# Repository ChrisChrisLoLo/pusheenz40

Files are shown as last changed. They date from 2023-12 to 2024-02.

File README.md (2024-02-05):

# pusheenz40
An experimental ultraportable pocket keyboard that uses low profile SMD mouse switches (EVQP0N02B) to achieve a compact form factor (8mm thick) while still being viable as a daily use keyboard (85+ wpm). Entire PCBA can be produced by JLCPCB. Uses 3D printed keycaps.

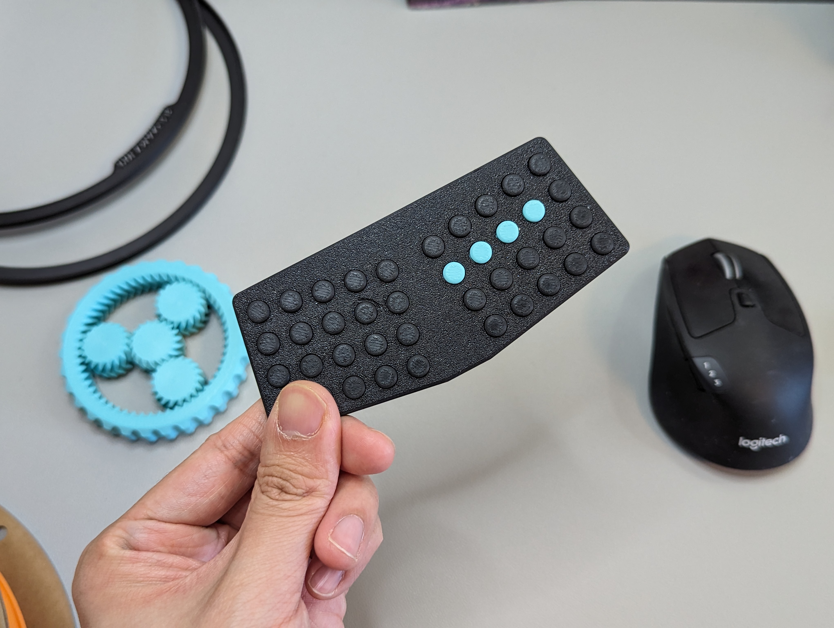
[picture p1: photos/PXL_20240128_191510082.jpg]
a photo of a pusheenz40


# Status
v0.0 PCBs are working! A pcb produced from the files should work.

Disclaimer is that this design has very low tolerances for its key switches. You will likely need a 3D printer such as a Bambu Lab A1/A1 mini/P1P/P1S and set the slicing layer resolution to 0.08mm. Printers like the Prusa i3/mini may also work, but have not been tested.

If you want to assemble/order your own PCBAs, come chat in the discord here! https://discord.gg/m8vwnqJEsc

# About
I hit the limit as how small I could go with choc switches. For my bunchiez40 and modkipz40, I used kailh mute switches as a smaller alternative. While a good start, these switches are both fairly tall and not super comfortable to type on directly. This board alternatively uses SMD EVQP0N02B switches from LCSC, which lowers the board height considerably, and reduces manual assembly required. This board also uses 3D printed buttons, which makes keypresses more comfortable.

More details about my research on mouse switches and experience with the pusheenz40 can be found here: https://chrischrislolo.github.io/orthoLabLogs/pusheenz40.html

Case files include 3MF files, STEP files that include the top case housing, as well as the buttons.

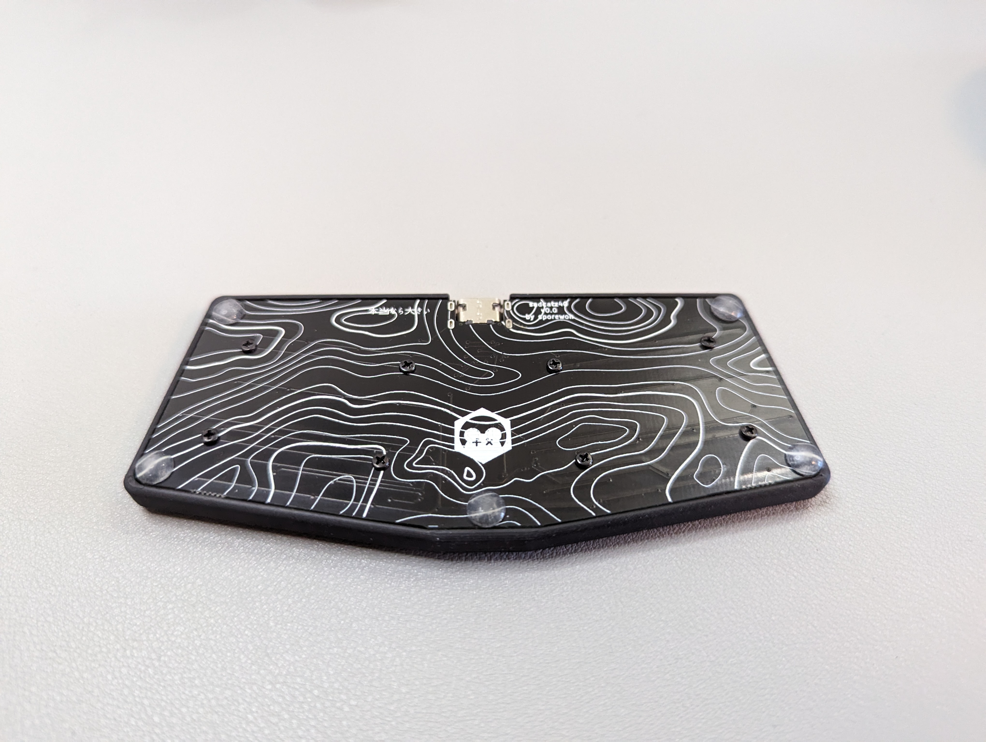
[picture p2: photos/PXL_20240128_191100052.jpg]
a pusheenz40


# Case
The case files can be found in the `case` directory. There is either the inverted rails or simple rails model to choose from. The simple rails model can be cnc'd, but has a rare tendency to have the buttons stick when pressed at a weird angle (1/1000 presses, as a rough guage of frequency). The inverted rails model has less of this issue, but cannot be cnc'd due to its sharp edges. I currently daily drive with the simple rails model.

3D printed cases can and should use the finest resolution possible on your printer, and ideally should use a higher end printer due to it's low tolerances. The models have been tested to work with the Bambu lab A1 and P1S at a layer height and detail setting of 0.08mm (extra fine). It's recommended to use a high quality and/or a newer printer.

Lubricating the case rails with something like krytox 205g0 is recommended, especially when using a CNC aluminum case. 

## PCB
You can find the PCB source files in the `pcb` folder. The BOM files can be found in this folder.

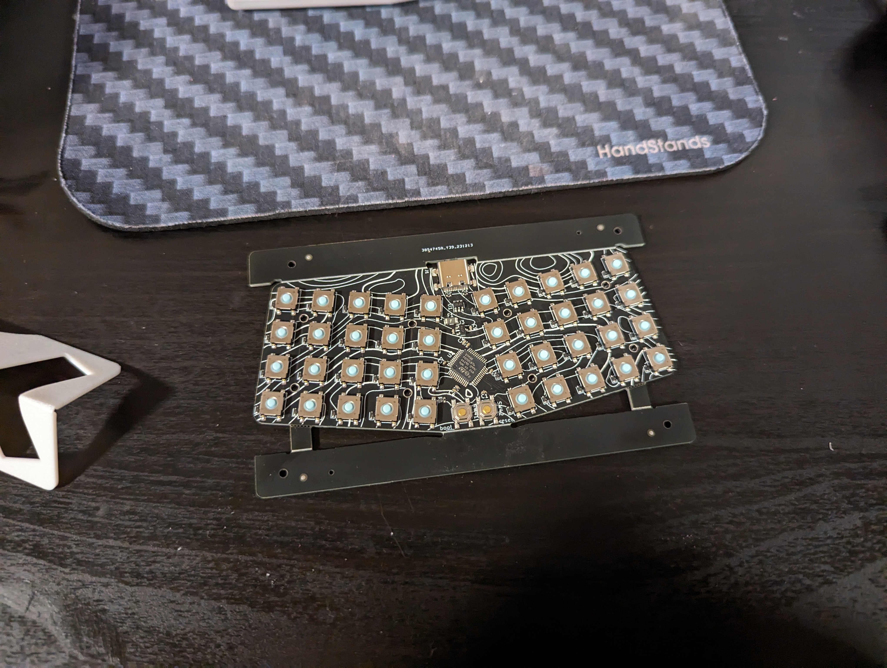
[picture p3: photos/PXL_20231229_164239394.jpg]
pusheenz40 pcb


## Directory Structure
- `case`
    You can find the files you need in this folder to print out a case for the keyboard
- `drafts`
    Stores any ergogen or intermediate information used in making the case
- `pcb`
    Kicad project relating to the project. Contains the BOM, placement files, and gerbers
   
## BOM
- 1 PCBA
  - The PCB will include all electrical parts required, including switches.
- 1 Aluminum CNC upper case or 3DP upper case
- 40 3D printed buttons
- 8 3mm M1.6 screws (go for flathead for a more flush fit, though other head types should also work)
- 4-8 (ideally 8) 1-2mm bumpons (something like Sj5302 is a good place to start)

## Assembly
Flash the pcb via QMK (see below section). Bootmagic is enabled, so using the top left key to flash from here on out is doable.

Pop the 3D printed buttons/keycaps into the case, and make sure they don't stick and can freely move up and down. If they do stick (e.g. need noticable force applied to pop out), confirm that you're printing at the finest detail setting. All keys need to be flush against the case. Once the switches are in place, over lap the pcb over the case. Gently press the pcb to make sure a button isn't pressed down.

Optionally wrap the board with a rubber band to hold it in place and flip it over to validate everything. Then gently press every button to make sure if it can actuate. If a button is very sticky, reprinting or sanding may be required. If there's slight friction on the keys return, this should slowly go away as the keyboard is broken in. If there's a button that won't actuate, it's possible that the button is misaligned. Flip the board back around, remove the rubber band and pcb, and make sure the problematic key is flush against the case. Place back pcb around and test until all keys properly acutate.

Then turn the keybard around one last time so the pcb is facing upwards. Screw on the screws and test one last time.

Finally, place on the rubber bumpons

## Firmware
QMK Firmware can be found here
https://github.com/ChrisChrisLoLo/vial-qmk/tree/sporewoh/keyboards/sporewoh/pusheenz40

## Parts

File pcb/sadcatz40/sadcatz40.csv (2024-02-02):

Id | Designator | Footprint | Quantity | Designation | Supplier and ref
1 | D36,D33,D10,D23,D17,D5,D37,D1,D4,D18,D12,D7,D22,D6,D2,D14,D11,D19,D39,D13,D31,D40,D16,D15,D29,D8,D38,D26,D27,D24,D9,D30,D25,D34,D32,D21,D28,D35,D20,D3 | D_SOD-523 | 40 | D_Small
2 | SW2,SW32,SW10,SW20,SW8,SW19,SW38,SW15,SW21,SW1,SW36,SW29,SW25,SW31,SW11,SW13,SW4,SW34,SW17,SW18,SW33,SW40,SW30,SW7,SW14,SW12,SW5,SW3,SW24,SW16,SW28,SW37,SW9,SW39,SW26,SW22,SW23,SW27,SW35,SW6 | SW_SPST_EVQP0 | 40 | SW_Push
3 | SW41 | SW_SPST_SKQG_WithoutStem | 1 | BOOT
4 | C10,C3,C9 | C_0402_1005Metric | 3 | 1uF
5 | U1 | SOT-23-6 | 1 | USBLC6-2SC6
6 | H3,H6,H2,H1,H4,H7,H8,H5 | m1.6_hole | 8 | MountingHole_Pad
7 | C7,C1,C5,C6,C4 | C_0402_1005Metric | 5 | 100nF
8 | R1 | R_0402_1005Metric | 1 | 10k
9 | C2 | C_0402_1005Metric | 1 | 4.7uF
10 | SW42 | SW_SPST_SKQG_WithoutStem | 1 | RST
11 | J1 | Mid_Mount-USB_C | 1 | USB2_C_Receptacle
12 | R2,R3 | R_0402_1005Metric | 2 | 5.1k
13 | U2 | LQFP-48_7x7mm_P0.5mm | 1 | STM32F072C8Tx
14 | U3 | SOT-23 | 1 | XC6206PxxxMR-Regulator_Linear
15 | F1 | Fuse_1206_3216Metric | 1 | 500mA

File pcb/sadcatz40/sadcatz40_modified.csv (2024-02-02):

Designator | Footprint | Comment | JLCPCB Part #
J1 | Mid_Mount-USB_C | USB2_C_Receptacle | C223907
C4,C6,C5,C1,C7 | C_0402_1005Metric | 100nF | C1525
D3,D20,D35,D28,D21,D32,D34,D25,D30,D9,D24,D27,D26,D38,D8,D29,D15,D16,D40,D31,D13,D39,D19,D11,D14,D2,D6,D22,D7,D12,D18,D4,D1,D37,D5,D17,D23,D33,D10,D36 | D_SOD-523 | D_Small | C145179
SW2,SW32,SW10,SW20,SW8,SW19,SW38,SW15,SW21,SW1,SW36,SW29,SW25,SW31,SW11,SW13,SW4,SW34,SW17,SW18,SW33,SW40,SW30,SW7,SW14,SW12,SW5,SW3,SW24,SW16,SW28,SW37,SW9,SW39,SW26,SW22,SW23,SW27,SW35,SW6 | SW_SPST_EVQP0 | SW_Push | C713479
C9,C3,C10 | C_0402_1005Metric | 1uF | C52923
F1 | Fuse_1206_3216Metric | 500mA | C163512
R3,R2 | R_0402_1005Metric | 5.1k | C25905
U3 | SOT-23 | XC6206PxxxMR-Regulator_Linear | C5446
U2 | LQFP-48_7x7mm_P0.5mm | STM32F072C8Tx | C80488
SW42 | SW_SPST_SKQG_WithoutStem | RST | C318884
C2 | C_0402_1005Metric | 4.7uF | C23733
R1 | R_0402_1005Metric | 10k | C25744
U1 | SOT-23-6 | USBLC6-2SC6 | C5250994
SW41 | SW_SPST_SKQG_WithoutStem | BOOT | C318884

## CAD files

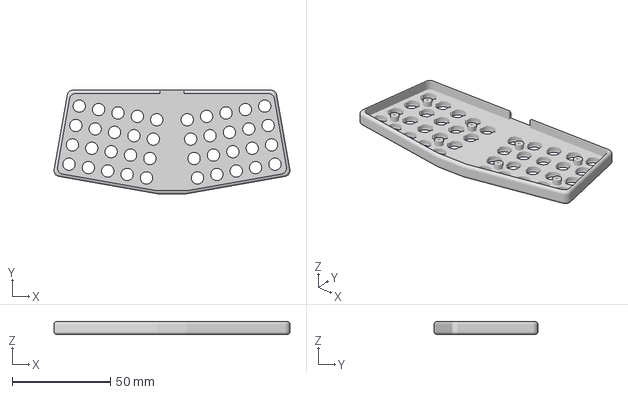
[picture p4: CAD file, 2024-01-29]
case/inverted_rails/pusheenz40 low tolerance v5 case.3mf
120.0 x 52.7 x 6.70 mm

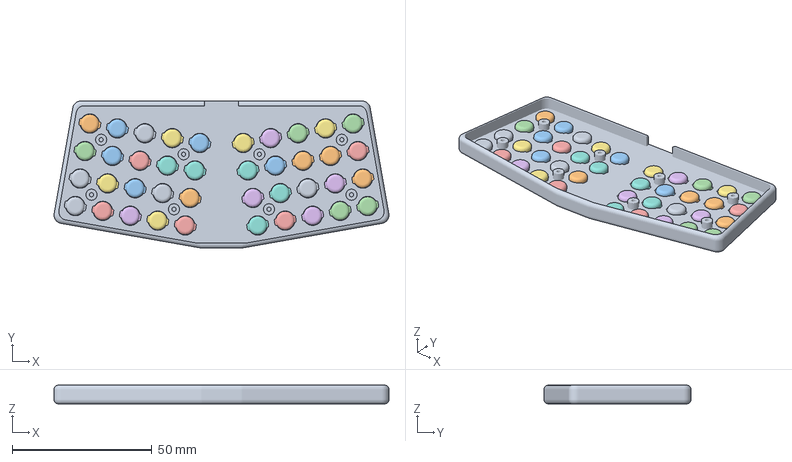
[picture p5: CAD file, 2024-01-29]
case/simple_rails/pusheenz40 low tolerance v2 v8.3mf
120.0 x 52.7 x 6.70 mm

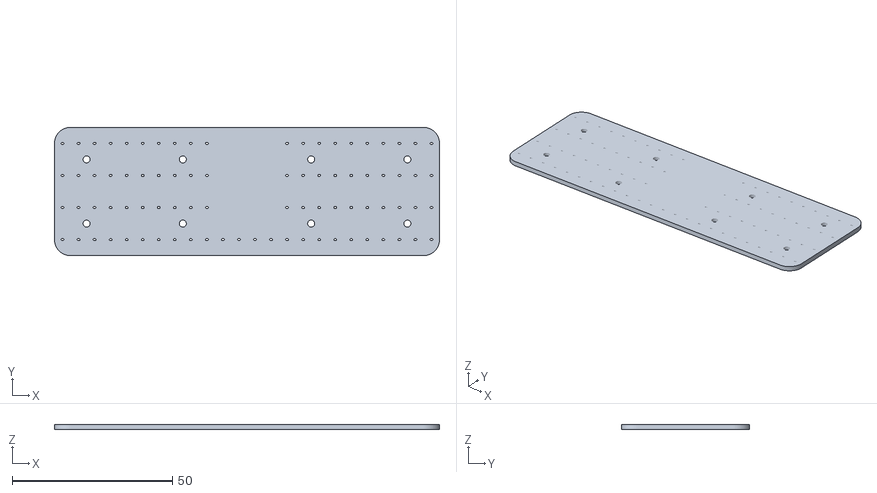
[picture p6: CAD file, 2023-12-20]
pcb/sadcatz40/pcb_prototype.stl
120.0 x 40.0 x 1.60

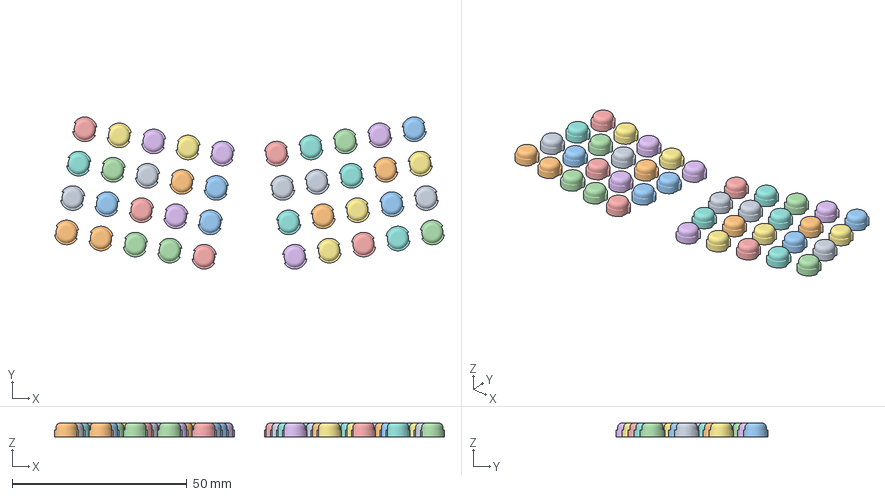
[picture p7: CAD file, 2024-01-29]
case/inverted_rails/pusheenz40 low tolerance v5.3mf
111.7 x 43.5 x 4.00 mm

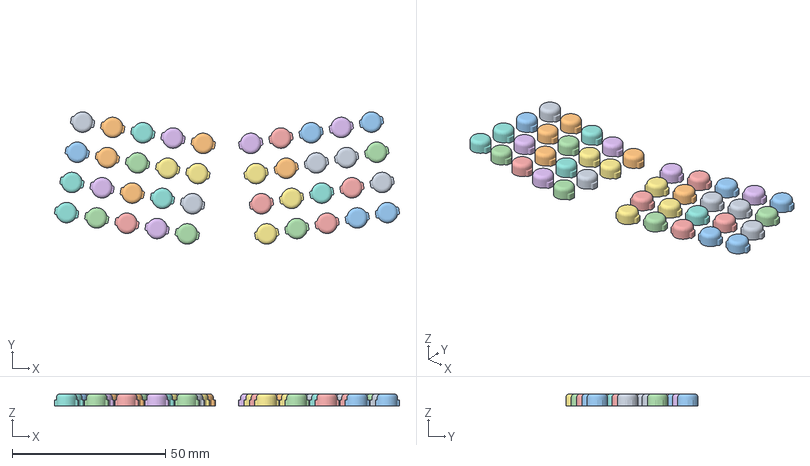
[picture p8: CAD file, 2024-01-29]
case/simple_rails/pusheenz40 low tolerance v2 v8 keycaps.3mf
112.6 x 43.2 x 4.00 mm

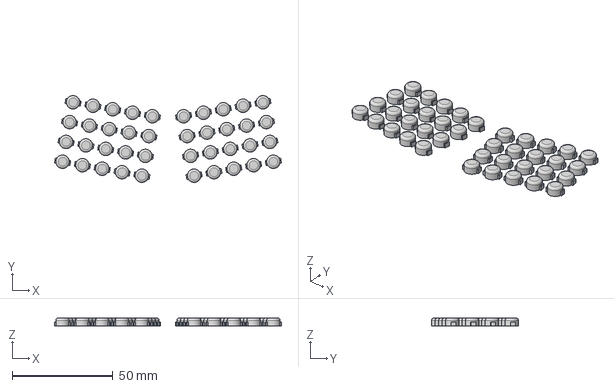
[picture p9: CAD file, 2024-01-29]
case/simple_rails/pusheenz40 low tolerance simple rails keycaps v4.step
112.8 x 43.2 x 4.00 mm

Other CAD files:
case/simple_rails/pusheenz40 low tolerance simple rails v4 body.step
case/inverted_rails/pusheenz40 low tolerance v5.f3d
case/simple_rails/pusheenz40 low tolerance v2 v8.f3d

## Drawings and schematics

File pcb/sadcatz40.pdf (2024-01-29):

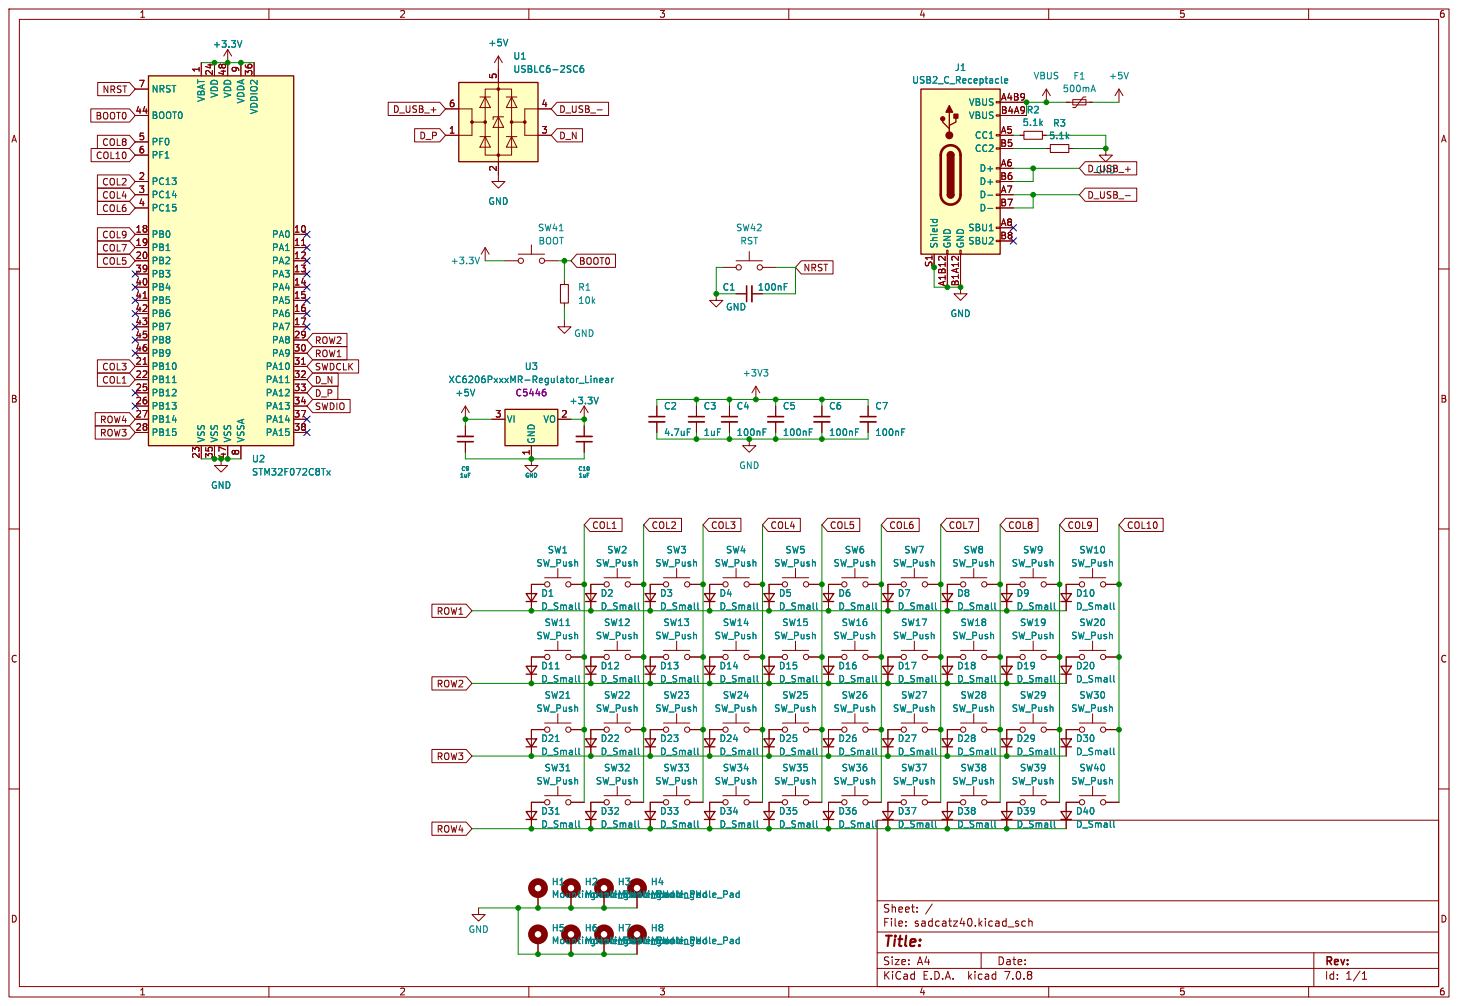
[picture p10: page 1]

1 PA0 10 PA1 11 PA2 12 PA3 13 PA4 14 PA5 15 PA6 16 PA7 17 PB0 18 PB1 19 PC13 2 PB2 20 PB10 21 PB11 22 VSS 23 VDD 24 PB12 25 PB13 26 PB14 27 PB15 28 PA8 29 PC14 3 PA9 30 PA10 31 PA11 32 PA12 33 PA13 34 VSS 35 VDDIO2 36 PA14 37 PA15 38 PB3 39 PC15 4 PB4 40 PB5 41 PB6 42 PB7 43 BOOT0 44 PB8 45 PB9 46 VSS 47 VDD 48 PF0 5 PF1 6 NRST 7 VSSA
10k GND

Id: 1/1 Title: File: sadcatz40.kicad_sch Sheet: / SW17 SW_Push SW27 SW_Push D17 D_Small R1

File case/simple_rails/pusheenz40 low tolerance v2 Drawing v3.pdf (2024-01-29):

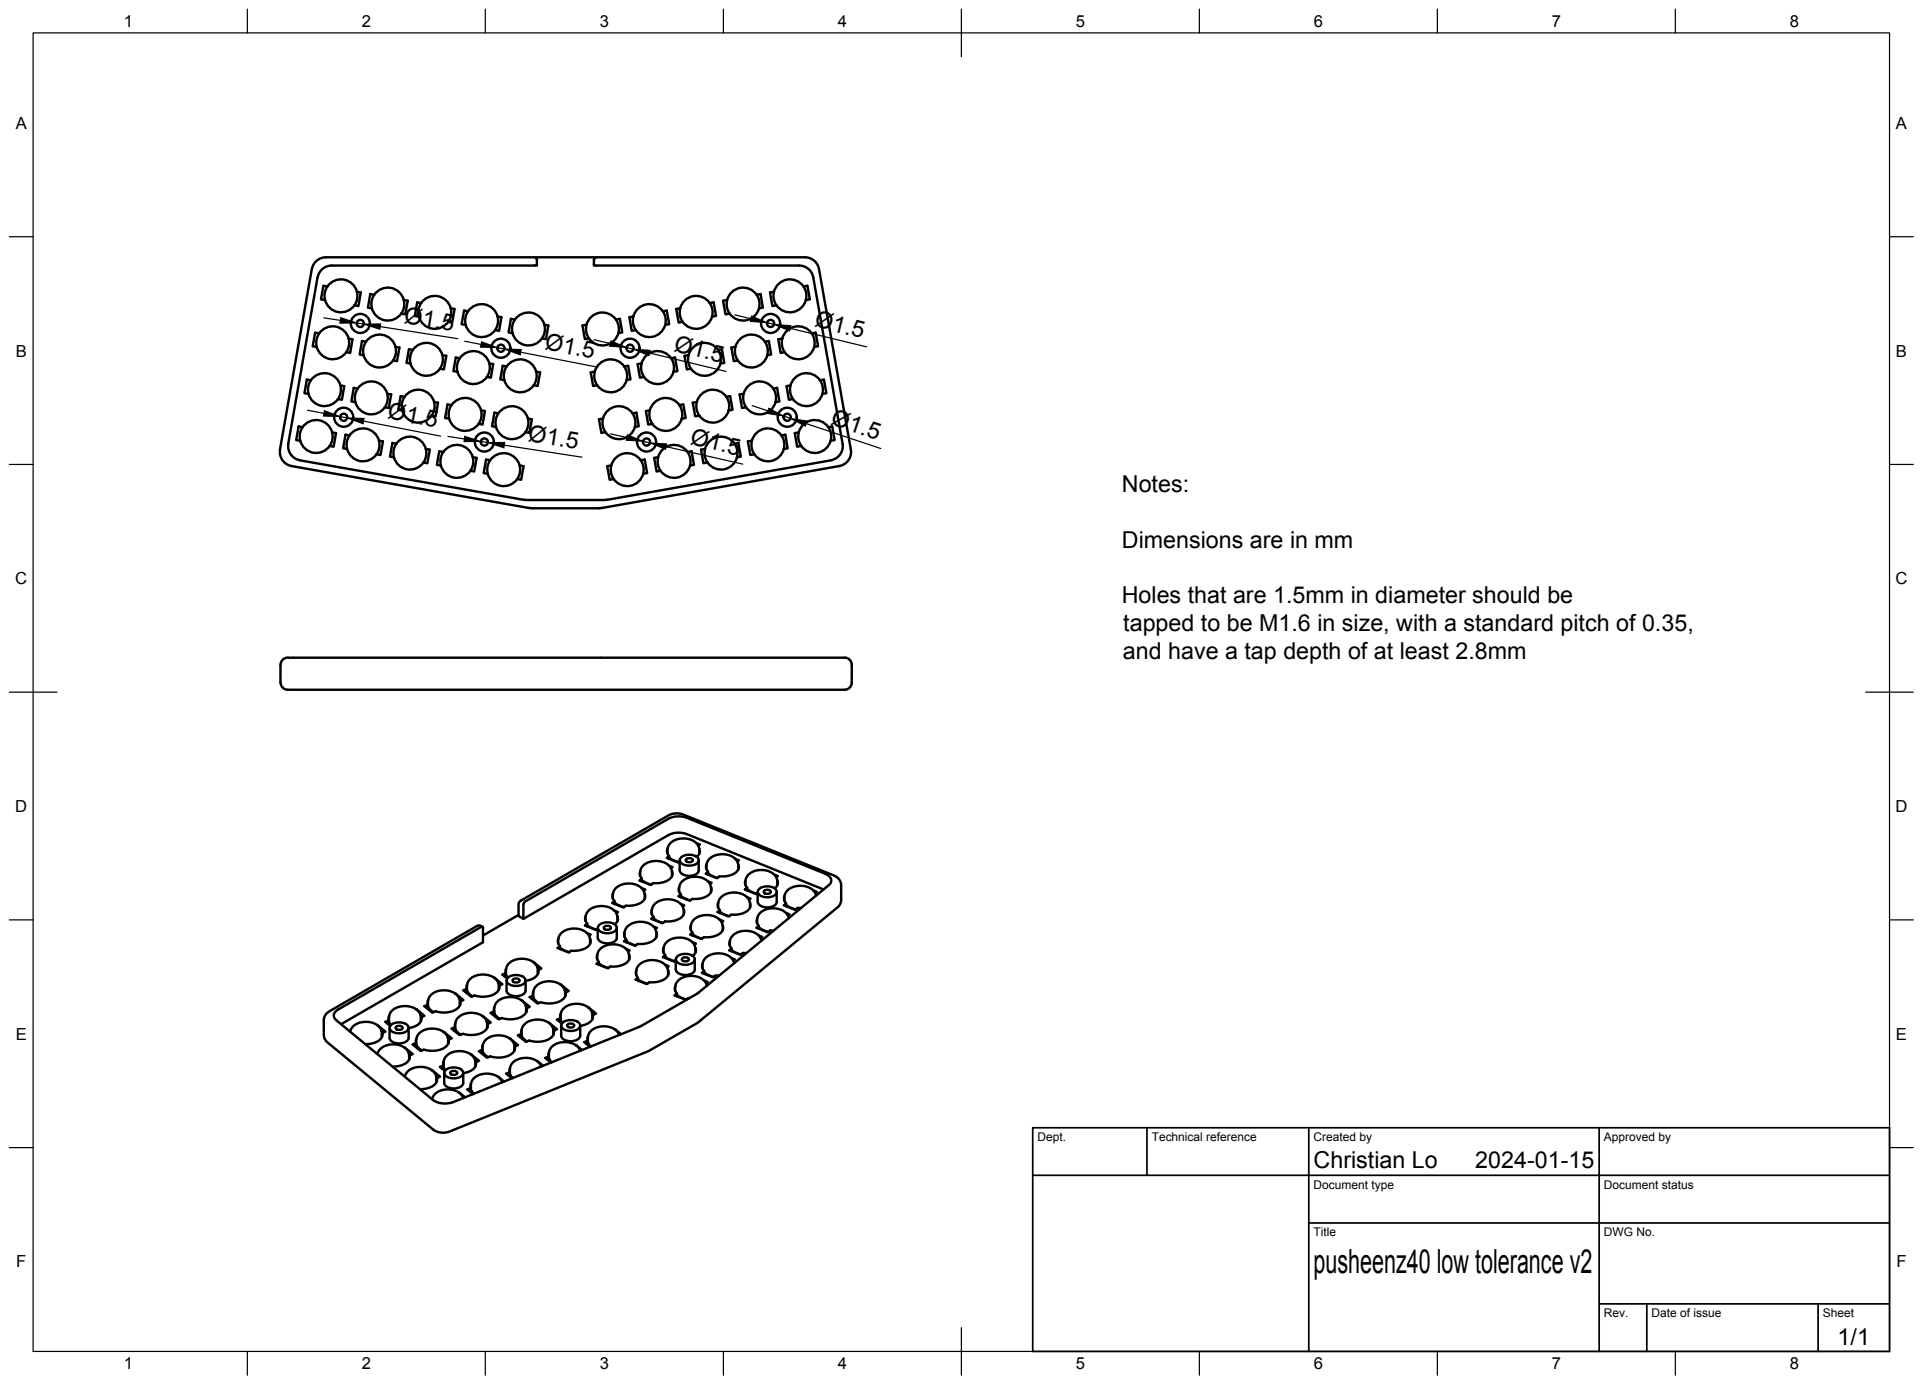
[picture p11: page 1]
Title; DWG No.; Rev.; Date of issue; Sheet; pusheenz40 low tolerance v2

Dimensions are in mm

Holes that are 1.5mm in diameter should be
tapped to be M1.6 in size, with a standard pitch of 0.35,
and have a tap depth of at least 2.8mm

Dept. | Technical reference | Created by Christian Lo 2024-01-15 | Approved by

Document type | Document status

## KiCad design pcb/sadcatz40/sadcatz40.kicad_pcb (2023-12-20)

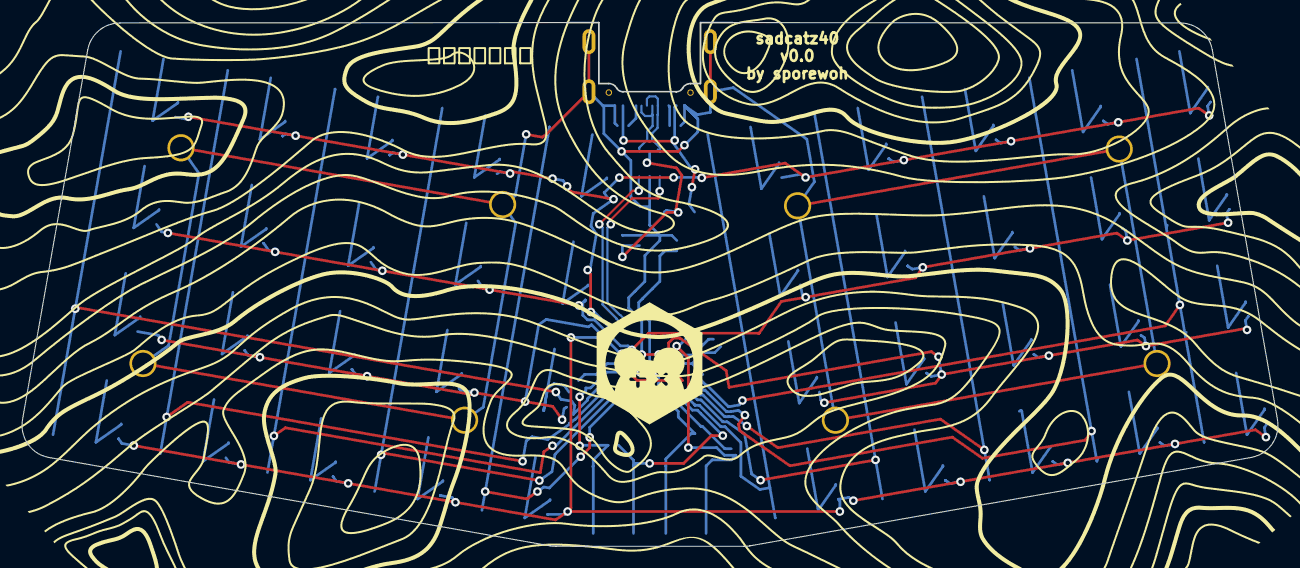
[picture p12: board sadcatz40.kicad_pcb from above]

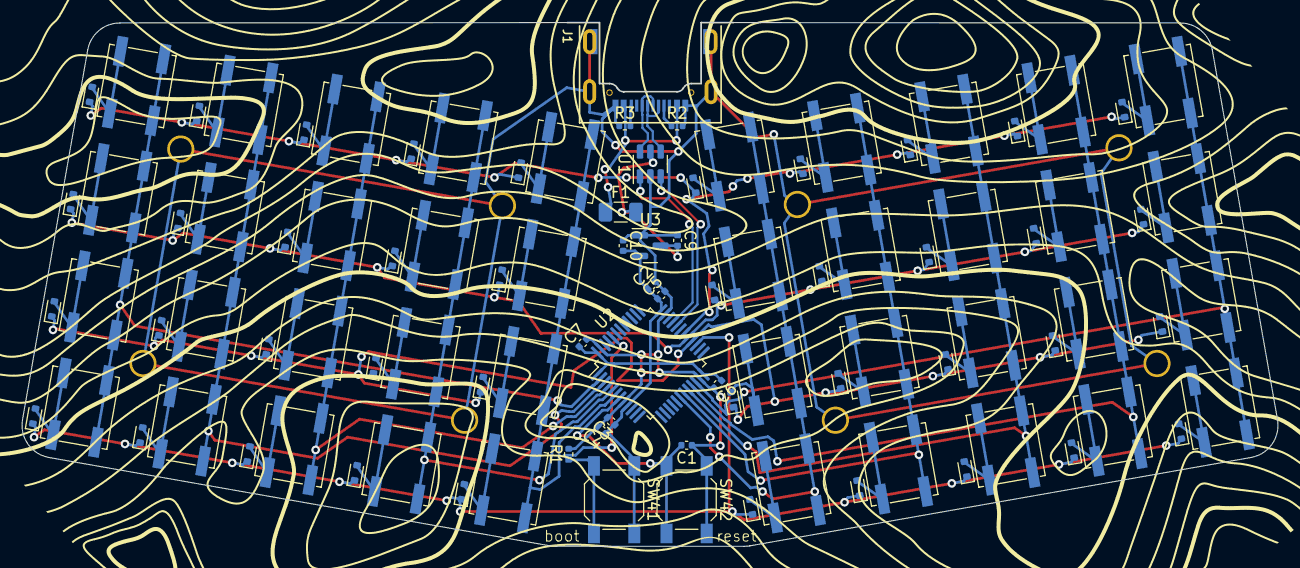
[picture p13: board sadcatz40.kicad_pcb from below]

Board: 2 copper layers, 115.4 x 48.1 mm, 107 parts (107 on the bottom side), 66 nets.

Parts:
C1, C4, C5, C6, C7: 100nF; C_0402_1005Metric
C2: 4.7uF; C_0402_1005Metric
C3, C9, C10: 1uF; C_0402_1005Metric
D1, D2, D3, D4, D5, D6, D7, D8, D9, D10, D11, D12, D13, D14, D15, D16, D17, D18, D19, D20, D21, D22, D23, D24, D25, D26, D27, D28, D29, D30, D31, D32, D33, D34, D35, D36, D37, D38, D39, D40: D_Small; D_SOD-523
F1: 500mA; Fuse_1206_3216Metric
H1, H2, H3, H4, H5, H6, H7, H8: MountingHole_Pad; m1.6_hole
J1: USB2_C_Receptacle; Mid_Mount-USB_C
R1: 10k; R_0402_1005Metric
R2, R3: 5.1k; R_0402_1005Metric
SW1, SW2, SW3, SW4, SW5, SW6, SW7, SW8, SW9, SW10, SW11, SW12, SW13, SW14, SW15, SW16, SW17, SW18, SW19, SW20, SW21, SW22, SW23, SW24, SW25, SW26, SW27, SW28, SW29, SW30, SW31, SW32, SW33, SW34, SW35, SW36, SW37, SW38, SW39, SW40: SW_Push; SW_SPST_EVQP0
SW41: BOOT; SW_SPST_SKQG_WithoutStem
SW42: RST; SW_SPST_SKQG_WithoutStem
U1: USBLC6-2SC6; SOT-23-6
U2: STM32F072C8Tx; LQFP-48_7x7mm_P0.5mm
U3: XC6206PxxxMR-Regulator_Linear; SOT-23

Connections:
+3V3: C2.1, C3.1, C4.1, C5.1, C6.1, C7.1, C10.2, SW41.1, U2.1 (VBAT), U2.9 (VDDA), U2.24 (VDD), U2.36 (VDDIO2), U2.48 (VDD), U3.2 (VO)
+5V: C9.2, F1.2, U1.5 (VBUS), U3.3 (VI)
BOOT0: R1.1, SW41.2, U2.44 (BOOT0)
COL1: SW1.2, SW11.2, SW21.2, SW31.2, U2.22 (PB11)
COL2: SW2.2, SW12.2, SW22.2, SW32.2, U2.2 (PC13)
COL3: SW3.2, SW13.2, SW23.2, SW33.2, U2.21 (PB10)
COL4: SW4.2, SW14.2, SW24.2, SW34.2, U2.3 (PC14)
COL5: SW5.2, SW15.2, SW25.2, SW35.2, U2.20 (PB2)
COL6: SW6.2, SW16.2, SW26.2, SW36.2, U2.4 (PC15)
COL7: SW7.2, SW17.2, SW27.2, SW37.2, U2.19 (PB1)
COL8: SW8.2, SW18.2, SW28.2, SW38.2, U2.5 (PF0)
COL9: SW9.2, SW19.2, SW29.2, SW39.2, U2.18 (PB0)
COL10: SW10.2, SW20.2, SW30.2, SW40.2, U2.6 (PF1)
D_N: U1.3 (I/O2), U2.32 (PA11)
D_P: U1.1 (I/O1), U2.33 (PA12)
D_USB_+: J1.A6 (D+), J1.B6 (D+), U1.6 (I/O1)
D_USB_-: J1.A7 (D-), J1.B7 (D-), U1.4 (I/O2)
GND: C1.1, C2.2, C3.2, C4.2, C5.2, C6.2, C7.2, C9.1, C10.1, H1.1, H2.1, H3.1, H4.1, H5.1, H6.1, H7.1, H8.1, J1.A1B12 (GND), J1.B1A12 (GND), J1.S1 (Shield), R1.2, R2.2, R3.1, SW42.1, U1.2 (GND), U2.8 (VSSA), U2.23 (VSS), U2.35 (VSS), U2.47 (VSS), U3.1 (GND)
NRST: C1.2, SW42.2, U2.7 (NRST)
unnamed: D1.2 (A), SW1.1
unnamed: D2.2 (A), SW2.1
unnamed: D3.2 (A), SW3.1
unnamed: D4.2 (A), SW4.1
unnamed: D5.2 (A), SW5.1
unnamed: D6.2 (A), SW6.1
unnamed: D7.2 (A), SW7.1
unnamed: D8.2 (A), SW8.1
unnamed: D9.2 (A), SW9.1
unnamed: D10.2 (A), SW10.1
unnamed: D11.2 (A), SW11.1
unnamed: D12.2 (A), SW12.1
unnamed: D13.2 (A), SW13.1
unnamed: D14.2 (A), SW14.1
unnamed: D15.2 (A), SW15.1
unnamed: D16.2 (A), SW16.1
unnamed: D17.2 (A), SW17.1
unnamed: D18.2 (A), SW18.1
unnamed: D19.2 (A), SW19.1
unnamed: D20.2 (A), SW20.1
unnamed: D21.2 (A), SW21.1
unnamed: D22.2 (A), SW22.1
unnamed: D23.2 (A), SW23.1
unnamed: D24.2 (A), SW24.1
unnamed: D25.2 (A), SW25.1
unnamed: D26.2 (A), SW26.1
unnamed: D27.2 (A), SW27.1
unnamed: D28.2 (A), SW28.1
unnamed: D29.2 (A), SW29.1
unnamed: D30.2 (A), SW30.1
unnamed: D31.2 (A), SW31.1
unnamed: D32.2 (A), SW32.1
unnamed: D33.2 (A), SW33.1
unnamed: D34.2 (A), SW34.1
unnamed: D35.2 (A), SW35.1
unnamed: D36.2 (A), SW36.1
unnamed: D37.2 (A), SW37.1
unnamed: D38.2 (A), SW38.1
unnamed: D39.2 (A), SW39.1
unnamed: D40.2 (A), SW40.1
unnamed: J1.A5 (CC1), R2.1
unnamed: J1.B5 (CC2), R3.2
ROW1: D1.1 (K), D2.1 (K), D3.1 (K), D4.1 (K), D5.1 (K), D6.1 (K), D7.1 (K), D8.1 (K), D9.1 (K), D10.1 (K), U2.30 (PA9)
ROW2: D11.1 (K), D12.1 (K), D13.1 (K), D14.1 (K), D15.1 (K), D16.1 (K), D17.1 (K), D18.1 (K), D19.1 (K), D20.1 (K), U2.29 (PA8)
ROW3: D21.1 (K), D22.1 (K), D23.1 (K), D24.1 (K), D25.1 (K), D26.1 (K), D27.1 (K), D28.1 (K), D29.1 (K), D30.1 (K), U2.28 (PB15)
ROW4: D31.1 (K), D32.1 (K), D33.1 (K), D34.1 (K), D35.1 (K), D36.1 (K), D37.1 (K), D38.1 (K), D39.1 (K), D40.1 (K), U2.27 (PB14)
VBUS: F1.1, J1.A4B9 (VBUS), J1.B4A9 (VBUS)

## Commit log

2023-12-20 init commit
    [modkipz40 bottom shell v16 bottom.step, modkipz40 bottom shell v16 plate.step, modkipz40 bottom shell v16.step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]
2023-12-23 tighten key tolerance
2023-12-25 tighten tolerances
2024-01-29 update pcb
    [modkipz40 bottom shell v16 bottom.step, modkipz40 bottom shell v16 plate.step, modkipz40 bottom shell v16.step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]
2024-01-29 add cases and readme
    [pusheenz40 low tolerance simple rails keycaps v4.step, pusheenz40 low tolerance simple rails v4 body.step, pusheenz40 low tolerance v2 v8 keycaps.3mf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]
2024-02-02 add bom and placement
    [sadcatz40-bottom-pos_modified.csv, sadcatz40.csv, sadcatz40_modified.csv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]
2024-02-03 add fusion360 source files B)
    [pusheenz40 low tolerance v2 v8.f3d, pusheenz40 low tolerance v5.f3d]
